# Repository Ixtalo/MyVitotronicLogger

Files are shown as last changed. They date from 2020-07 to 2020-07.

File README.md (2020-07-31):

MyVitotronicLogger
==================
Vissmann boiler logger with DIY OptoLink interface.  

AST, 12.03.2019

Motivation
----------
For a Vissmann boiler with a control interface Vitotronic 200 KW1 (V200KW1):   
* How much energy is consumed?
* How to monitor the boiler's temperatures?
* What is the boiler doing over time?
* How to interface with the boiler?

(DE) "Witterungsgeführte Kesselregelung für gleitend abgesenkte Kesselwassertemperatur"  

Solution Approach
-----------------
* Use the optical maintenance interface of the Vitotronic control interface.
	* <https://github.com/openv/openv/wiki/Die-Optolink-Schnittstelle>
	* KW Protocol, <https://github.com/openv/openv/wiki/Protokoll-KW>
* Use Arduino ESP8266 with a DIY optocoupler interface, see <https://github.com/openv/openv/wiki/Bauanleitung-ESP8266>
* Use VitoWiFi library
	* Arduino Library for ESP8266 to communicate with Viessmann boilers using a (DIY) serial optolink.
	* <https://github.com/bertmelis/VitoWiFi.git>
    * Many thanks for this gread library!
	* Based on the fantastic OpenV library

Requirements
------------
* ESP8266, e.g., Wemos D1 Mini
* OptoLink interface: <https://github.com/openv/openv/wiki/Bauanleitung-ESP8266>
* Libraries for:
	* Arduino, e.g., *Arduino IDE*
	* ESP8266 / Wemos D1 Mini
	* VitoWiFi, <https://github.com/bertmelis/VitoWiFi>
		* Tested working version was [Version 1.0.2 from 10.11.2018](https://github.com/bertmelis/VitoWiFi/tree/5d8a2d5b270df575b2cb3b8847567947bac362e9)
* Optional: RS232 USB cable for Serial1 observation (attach to D4)

Circuit / Wiring
----------------
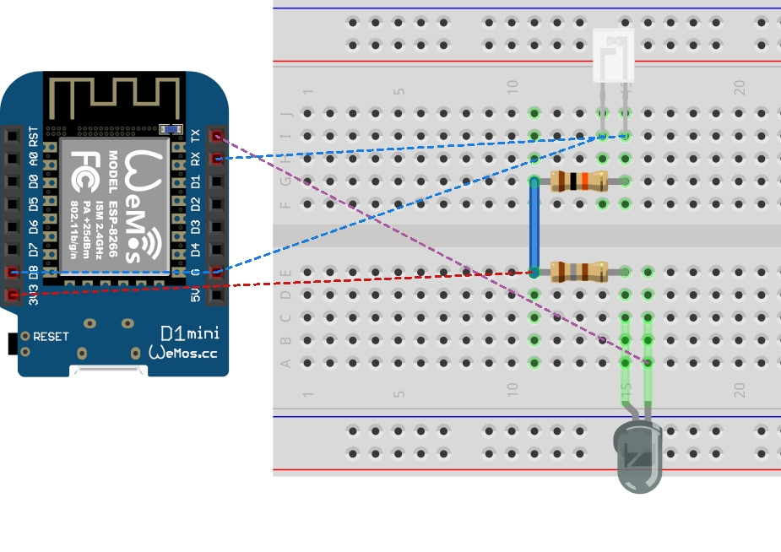
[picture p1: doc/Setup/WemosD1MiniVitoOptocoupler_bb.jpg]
Breadboard
  

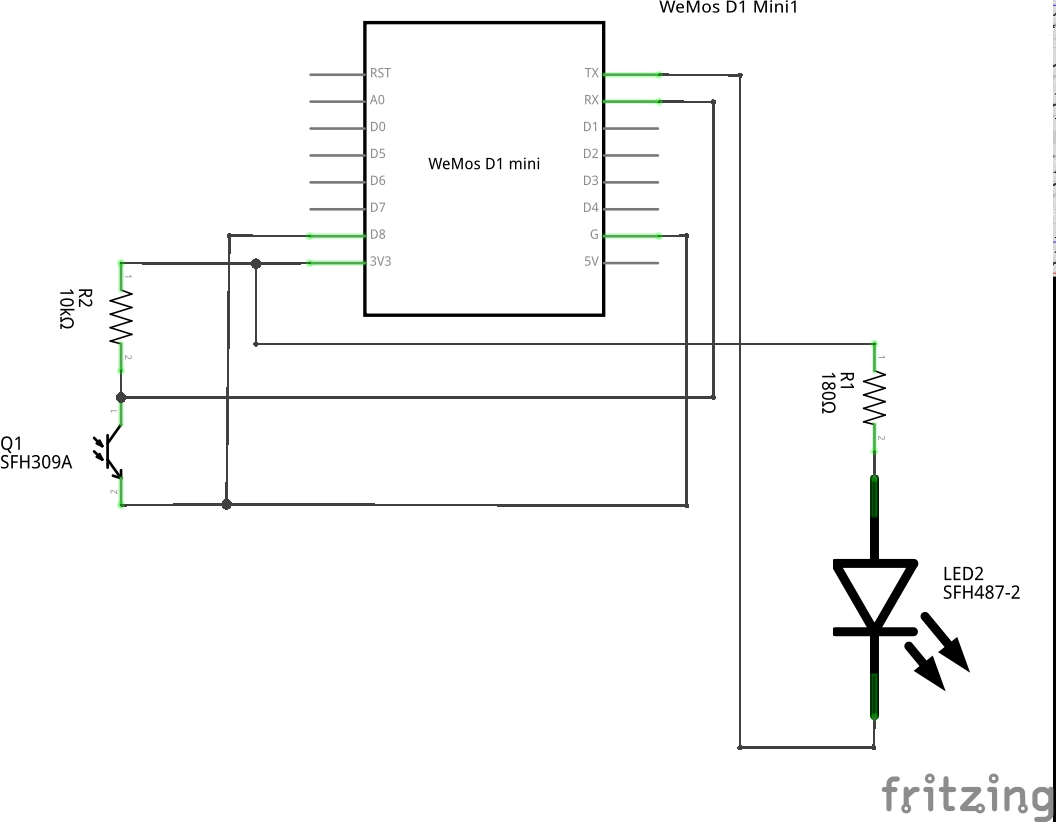
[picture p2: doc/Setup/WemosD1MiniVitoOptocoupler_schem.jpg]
Schematic


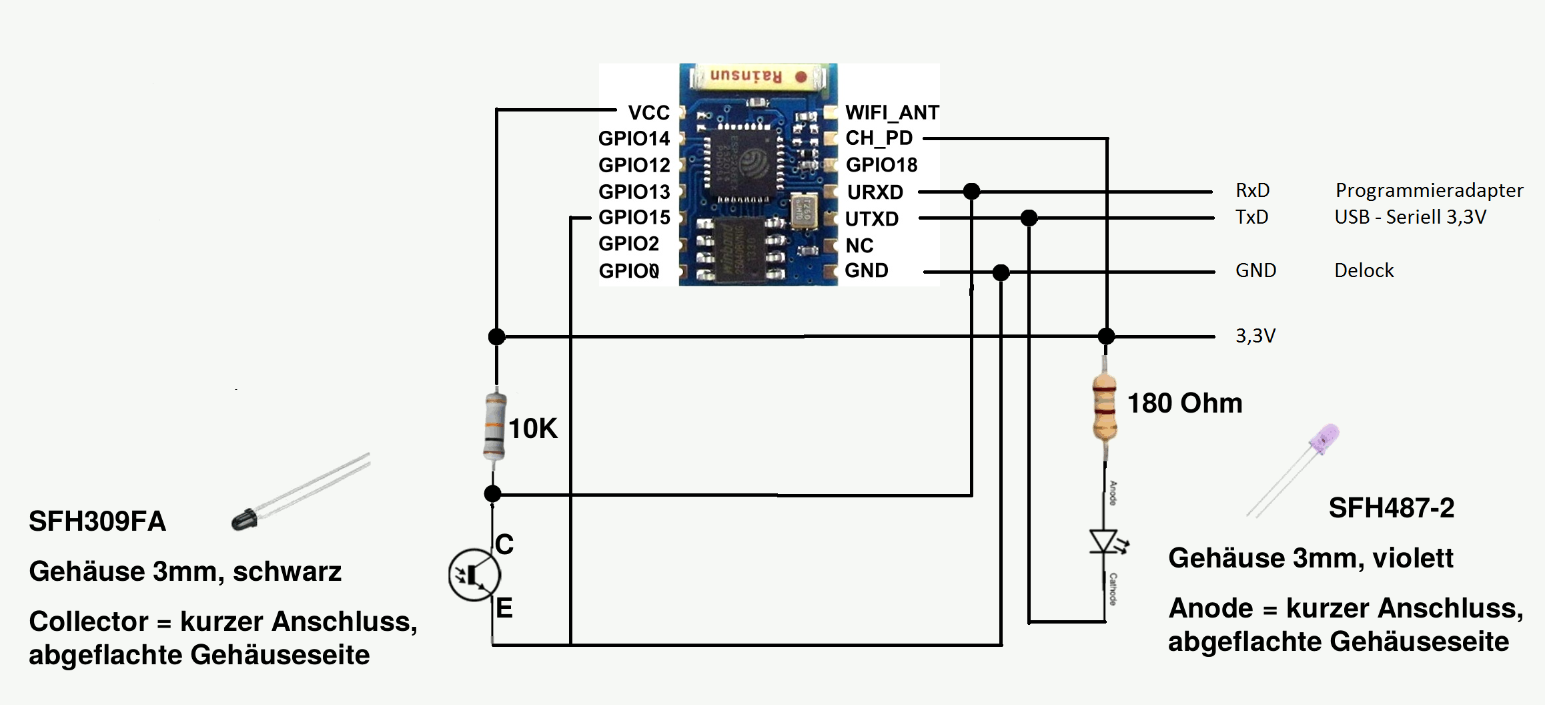
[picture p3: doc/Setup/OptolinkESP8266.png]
Wiring
  
(See also https://github.com/openv/openv/wiki/Bauanleitung-ESP8266)  

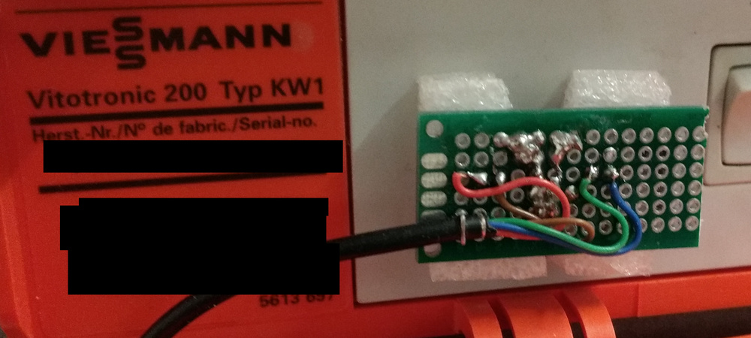
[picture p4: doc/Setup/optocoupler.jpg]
Sensor Breadboard Prototype


Debugging
---------------
1. Attach to opto coupler 
2. Attach RS232 USB cable to D4 to listen for Serial1 messages. **Serial1/UART1 TX pin is D4.**

**Do not connect to RX/TX because those are reserved for opto-coupler communication!**

For debugging the Serial1 Arduino software UART is being used.

  > Serial1.begin(115200);

All logging and status messages are being print using `Serial1.print`.  
Serial1 uses UART1 which is a transmit-only UART.  

Development
---------------

### vitowifitests
Testing project to test the OptoLink interface.
1. Attach to opto coupler 
2. Attach RS232 USB cable to D4 to listen for Serial1 messages. **Serial1/UART1 TX pin is D4.**

Example output:
```
temperature - boilerTemp is 32.4
temperature - STS1 is 48.5
temperature - RTS is 20.0
temperature - AGTS is 20.0
temperature - RLTS is 20.0
temperature - VLTS is 20.0
temperature - setRoomTemp is 309.2
temperature - setRoomReducedTemp is 513.2
burner - runHours is 10272.3
burner - starts is 199182
operation - currentOperatingMode is 2
pump - a1m1Pump is true
pump - storePump is false
pump - circuitPump is false
```

### vitowifimqtt
Working Arduino project.
Sends collected data from OptoLink interface to MQTT server.  

Example output:
```
/esp/VitoWiFi/ip 192.168.1.108
/esp/VitoWiFi/outsideTemp 8.9
/esp/VitoWiFi/boilerTemp 56.6
/esp/VitoWiFi/STS1 47.7
/esp/VitoWiFi/RTS 20.0
/esp/VitoWiFi/AGTS 20.0
/esp/VitoWiFi/RLTS 20.0
/esp/VitoWiFi/VLTS 20.0
/esp/VitoWiFi/setRoomTemp 309.2
/esp/VitoWiFi/setRoomReducedTemp 538.8
/esp/VitoWiFi/runHours 10274.3
/esp/VitoWiFi/starts 199237
/esp/VitoWiFi/currentOperatingMode 2
/esp/VitoWiFi/a1m1Pump true
/esp/VitoWiFi/storePump false
/esp/VitoWiFi/circuitPump false
```

### Pictures

My setup and wiring:
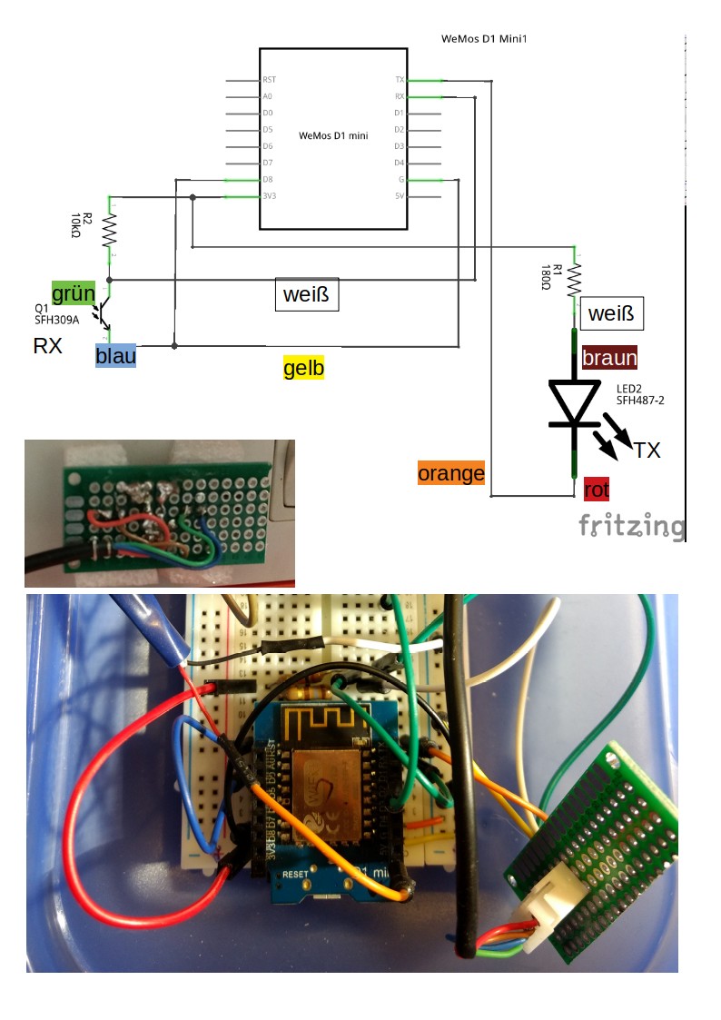
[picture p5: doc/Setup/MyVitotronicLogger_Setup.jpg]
My setup


Links
-----
* [OpenV](https://github.com/openv/openv/wiki/)
* [Anbindung der Heizungssteuerung über Optolink](https://www.harrykellner.de/index.php/projekte2/81-optolink)
* [Talking to Viessmann Vitodens 200](https://www.edom-plc.pl/index.php/en/1-wire-i-rpi-en/175-komunikacja-z-viessmann-em-vitodens-200)
* <http://www.rainer-rebhan.de/proj_vvt_manager.html>

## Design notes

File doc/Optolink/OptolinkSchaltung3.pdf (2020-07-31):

## Bauanleitung für eine Optolink Schnittstelle

## 1. Schaltplan (Schaltung 3)

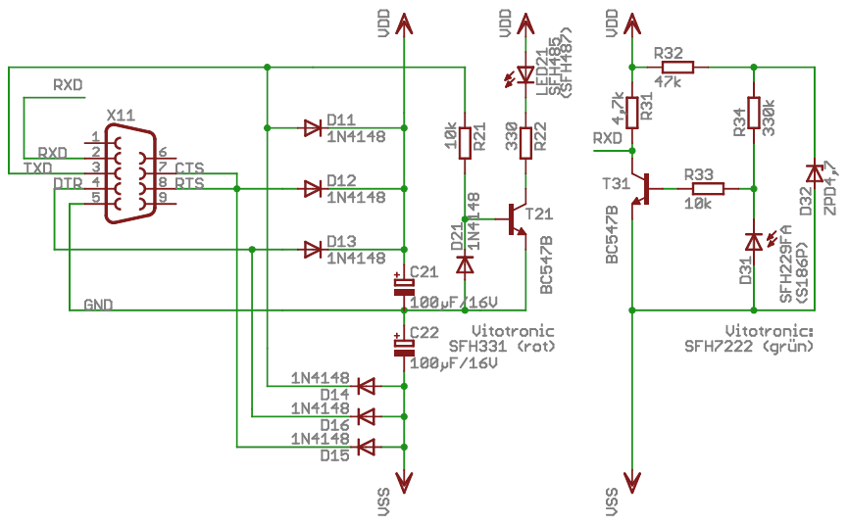
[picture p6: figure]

Bild 1: Schaltplan für Optolink Schnittstelle

Die Schaltung wurde im Vergleich zur ursprünglichen Schaltung in folgenden Punkten modifiziert:
- Einführung einer zusätzlichen negativen Spannung für die Empfangsdiode, um die Pegeldefinitionen der seriellen Schnittstelle einzuhalten (C22, D14-D16).
- Die Empfangsdiode wurde an die richtige Stelle versetzt und gedreht (Betrieb in Sperrrichtung).

## Stückliste

Bauteil | Wert | Beschreibung
C21 | 100µF/16V | Elektrolytkondensator
C22 | 100µF/16V | Elektrolytkondensator
D11-D16 | 1N4148 | Diode
D21 | 1N4148 | Diode
D31 | SFH229FA | Photodiode
D32 | ZPD4,7 | Zenerdiode 4,7 V
LED21 | SFH485 | Infrarot LED (5 mm), alternativ SFH487 (3 mm)
R21 | 10k | Widerstand
R22 | 330 | Widerstand
R31 | 4,7k | Widerstand
R32 | 47k | Widerstand
R33 | 10k | Widerstand
R34 | 330k | Widerstand
T21 | BC547B | NPN Transistor
T31 | BC547B | NPN Transistor
X11 | - | SUB-D Stecker 9-pol (weibl.)
| Stecker-
| gehäuse | Längeres Steckergehäuse für SUB-D Stecker
| Gehäuse | Bopla U50 50x50x30 mm
| Kabel | 5-adriges Kabel mit Schirm
| Zugentlastung | Gummitülle für Zugentlastung
Alle Widerstände 0,25 W, Gehäuse bestellbar bei Conrad (Bopla Nr. 06050000, Conrad Nr. 519979-62).
Seite 1 von 4 | Optolink Schaltung 3 V1.0

Technische Daten der Bauteile, etc.

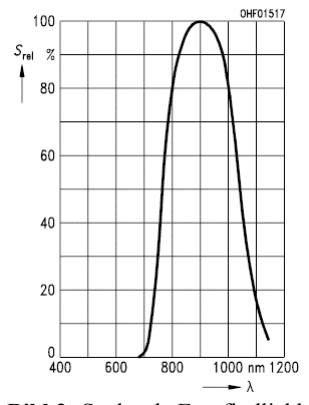
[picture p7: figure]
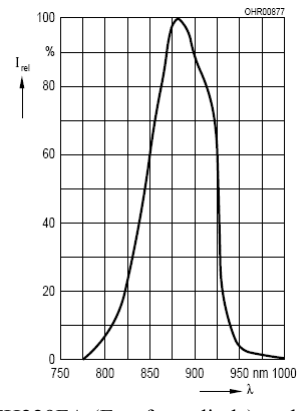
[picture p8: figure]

Bild 2: Spektrale Empfindlichkeit SFH229FA (Empfangsdiode) und spektrale Emission SFH485 (Sendediode)

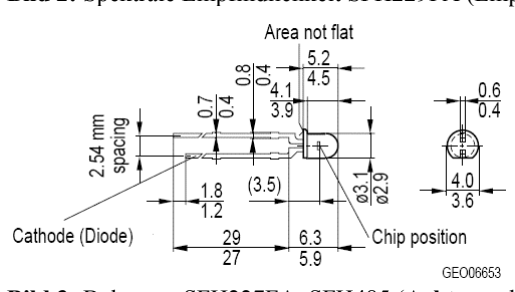
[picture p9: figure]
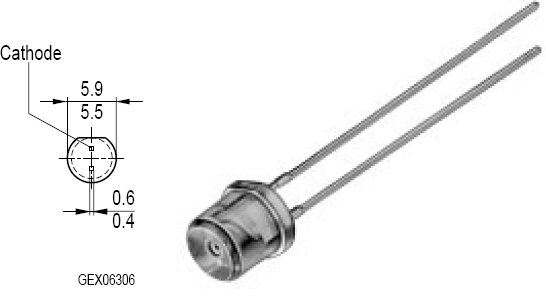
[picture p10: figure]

Bild 3: Belegung SFH227FA, SFH485 (Achtung: langes Beinchen ist Kathode!)

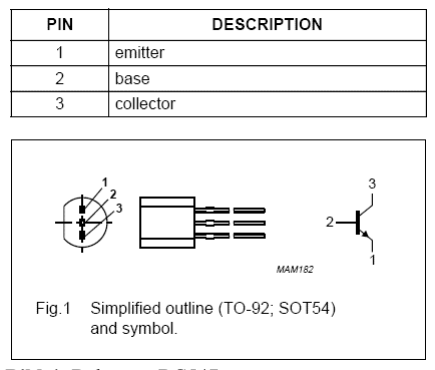
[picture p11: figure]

Bild 4: Belegung BC547

## 2. Mechanischer Aufbau

Im Folgenden soll nur stichwortartig der Aufbau geschildert werden, näheres bitte den Bildern entnehmen.
- An der Regelung die Maße für die Löcher und das V über ein Papier abnehmen und auf das Gehäuse übertragen.
- Die zwei Löcher für die Sende- bzw. Empfangsdiode bohren (Durchmesser und Position beachten).
- Das V in der Vitotronic mit Hilfe eines Kunststoffes, der für Abdeckung von Ausbrüchen in Zählerschränken verwendet wird, gestalten: In den Enden des V zwei Löcher bohren, die Abdeckung falten, mit dem Teppichmesser bearbeiten (zwei Zapfen stehen lassen) und in das Gehäuse einkleben.
- Die Schaltung C21, C22, D11-16 auf einer Lochrasterplatine, den Rest auf einer anderen Lochrasterplatine aufbauen.
- Beide mit Kabel verbinden und in die jeweiligen Gehäuse einbauen, Zugentlastung nicht vergessen.
Seite 2 von 4 | Optolink Schaltung 3 V1.0

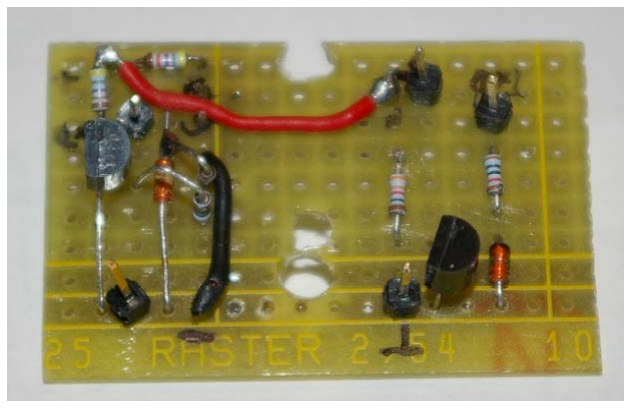
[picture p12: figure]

Bild 5: Lochrasterleiterplatte (Sende-/Empfangsteil)

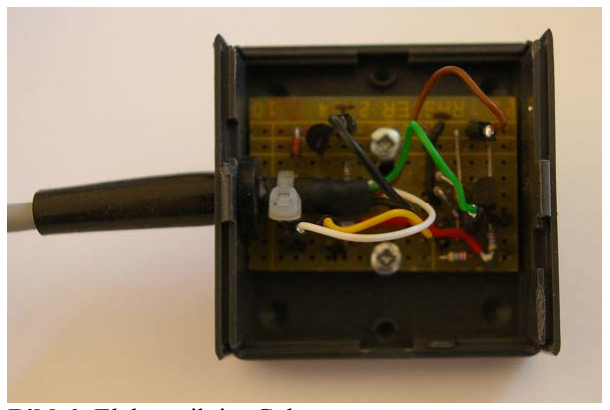
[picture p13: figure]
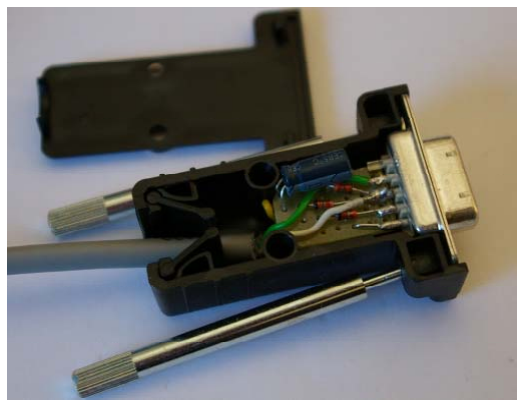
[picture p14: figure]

Bild 6: Elektronik im Gehäuse

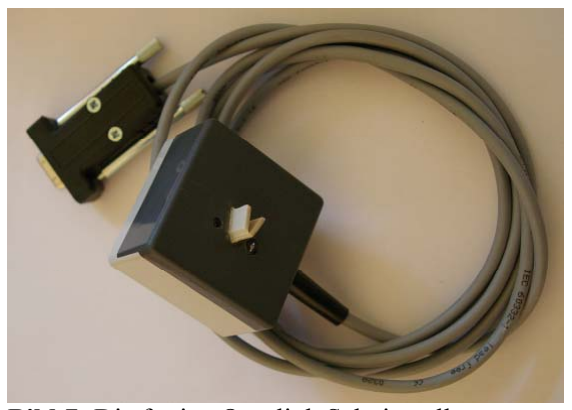
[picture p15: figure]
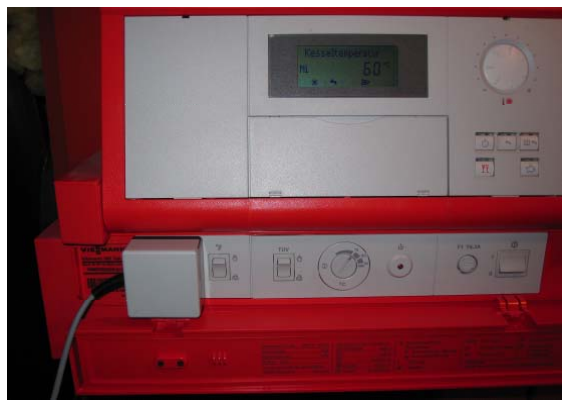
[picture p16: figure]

Bild 7: Die fertige Optolink Schnittstelle

## 3. Inbetriebnahme

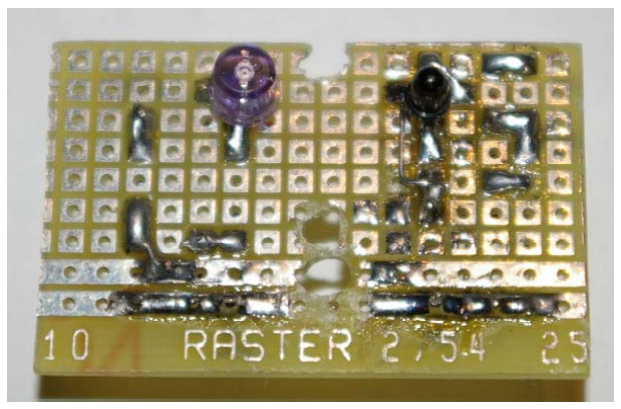
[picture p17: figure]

Wenn nach dem Aufbau soweit alles in Ordnung ist, kann die Schaltung statisch mit dem COM Tester von Arne Rossius¹
(aktuelle Version V1.0) getestet werden. Programm in beliebiges Verzeichnis auspacken und starten. COM Port auswählen, DTR und RTS an- bzw. ausschalten und die pos. bzw. neg. Versorgungsspannung messen. Dann TXD anschalten und messen, ob sich der Pegel am Kollektor von T21 ändert. Das Empfangen von Daten kann mit diesem Programm nicht getestet werden.

1 http://elektronik-kompendium.de/public/arnerossius/programme/windows/sertest1.zip, Stand 07.01.2010

Seite 3 von 4 | Optolink Schaltung 3 V1.0

Für den Test des Empfangs können verschiedene Terminalprogramme verwendet werden:
- COMTestSerial der Fa. MicroRidge (aktuelle Version 2.1)²
- SerialPortTerminal³
- RS232Test

4

Die Schnittstelle wird mit 4800 bps, 8 Bits, Even Parity, 2 Stopbits (4800, 8, E, 2) betrieben. Hardware Handshake wird nicht unterstützt. Software Handshake (XON/XOFF) wird nicht unterstützt und muss abgeschaltet werden, da sonst eine Datenbyte, das zufällig dem XOFF Zeichen entspricht, das Handshake stoppen könnte.

Terminalprogramm installieren, serielle Schnittstelle auswählen und Parameter für die Schnittstelle einstellen. Wichtig ist auch, dass man RTS oder DTR anschaltet, da ansonsten keine Spannung zur Verfügung steht. Wenn dann in regelmäßigen Abständen 05hex (ca. alle 2 ... 5 s) im Terminalprogramm angezeigt wird, so empfängt das Terminalprogramm korrekt die Daten, die von der Viessmann Regelung kommen. Die Optolink Schaltung funktioniert.

## 4. Rechtliches

Die einwandfreie Funktion der Schaltung wurde bei mir an einer Viessmann Vitotronik 200 KW1 nachgewiesen. Trotzdem hafte ich nicht für die ordnungsgemäße Funktion der Schaltung beim Nachbau. Ich schließe auch jede Haftung für Schäden, die sich beim Nachbau oder Betrieb der Schaltung ergeben, ausdrücklich aus.
Sollten sich Fehler in der Dokumentation eingeschlichen haben oder Fragen zum Aufbau auftauchen, dann bitte ich um eine kurze Mail an

palaretta@gmx.de

Ich bitte um Verständnis, wenn die Beantwortung der Fragen nicht sofort erfolgt.

Raum Heilbronn, 07.01.2010, Peter

2 http://www.microridge.com/comtestserial.htm, Stand 07.01.2010 3 http://www.logview.info/cms/download.php?f=81e020332a53570debd35e46b8f23b84, Stand 07.01.2010 4 http://openv.wikispaces.com/file/view/RS232Test.zip, Stand 07.01.2010, Programm funktioniert bei mir nicht!

Seite 4 von 4 | Optolink Schaltung 3 V1.0

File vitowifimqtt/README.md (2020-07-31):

# VitoWifiMqtt

Read Vissmann boiler parameters with a ESP8266 and a DIY opto-coupler interface.  

## Prerequisites

- VisualStudio Code (VSCode)
- PlatformIO

## How-To Build
1. Generate private key for signing (`private.key`). See https://arduino-esp8266.readthedocs.io/en/latest/ota_updates/readme.html#signed-binary-prerequisites

    > openssl genrsa -out private.key 2048
    > openssl rsa -in private.key -outform PEM -pubout -out public.key

    Adjust option `signing_private_key` in `platformio.ini` to point to you `private.key` file.

    > signing_private_key = $SMARTHOME_WORKSPACE/private.key 

2. Open folder in VSCode
3. Open PlatformIO
4. Build
5. The signed binary is `vitowifimqtt/.pio/build/d1_mini/firmware.bin.signed`

## Debug Output

### NoWiFi
```
SDK:2.2.2-dev(38a443e)/Core:2.6.3=20603000/lwIP:STABLE-2_1_2_RELEASE/glue:1.2-16-ge23a07e/BearSSL:89454af
Boot mode: 1
Reset reason: Deep-Sleep Wake
Connecting WiFi ...
scandone
no Tintagel.dev found, reconnect after 1s
reconnect
scandone
no Tintagel.dev found, reconnect after 1s
reconnect
scandone
no Tintagel.dev found, reconnect after 1s
WiFi wifi_res: 1
DeepSleep! (30.0 sec)
del if0
usl
enter deep sleep
```

### WiFi, No DHCP
```
DK:2.2.2-dev(38a443e)/Core:2.6.3=20603000/lwIP:STABLE-2_1_2_RELEASE/glue:1.2-16-ge23a07e/BearSSL:89454af
Boot mode: 1
Reset reason: Deep-Sleep Wake
tstart: 85
Connecting WiFi ...
scandone
scandone
state: 0 -> 2 (b0)
state: 2 -> 3 (0)
state: 3 -> 5 (10)
add 0
aid 1
cnt 

connected with Tintagel.dev, channel 1
dhcp client start...
WiFi wifi_res: -1
DeepSleep! (30.0 sec)
state: 5 -> 0 (0)
rm 0
del if0
usl
enter deep sleep
```

### WiFi, DHCP, No MQTT
```
SDK:2.2.2-dev(38a443e)/Core:2.6.3=20603000/lwIP:STABLE-2_1_2_RELEASE/glue:1.2-16-ge23a07e/BearSSL:89454af
Boot mode: 1
Reset reason: Deep-Sleep Wake
tstart: 83
Connecting WiFi ...
scandone
state: 0 -> 2 (b0)
state: 2 -> 3 (0)
state: 3 -> 5 (10)
add 0
aid 1
cnt 

connected with Tintagel.dev, channel 1
dhcp client start...
ip:192.168.99.128,mask:255.255.255.0,gw:192.168.99.1
WiFi connect result time: 4125
WiFi wifi_res: 3
OTA update check ...
[OTA]  HTTP update fatal error code -1
HTTP_UPDATE_FAILD Error (-1): HTTP error: connection refused
OTA update check END.
Attempting MQTT connection...failed, rc=-2
failed, rc=-2
pm open,type:2 0
failed, rc=-2
WiFi disconnect ...
state: 5 -> 0 (0)
rm 0
pm close 7
DeepSleep! (30.0 sec)
del if0
usl
enter deep sleep
```

### OTA HTTP request
```
Connection from 192.168.99.128 52336 received!
GET /firmware.bin HTTP/1.0
Host: 192.168.99.1:8266
User-Agent: ESP8266-http-Update
Connection: close
x-ESP8266-Chip-ID: 2713345
x-ESP8266-STA-MAC: xxx
x-ESP8266-AP-MAC: xxx
x-ESP8266-free-space: 2797568
x-ESP8266-sketch-size: 346400
x-ESP8266-sketch-md5: e4fa3ca3d5b1ca2a9892513ec5f4b3ee
x-ESP8266-chip-size: 4194304
x-ESP8266-sdk-version: 2.2.2-dev(38a443e)
x-ESP8266-mode: sketch
Content-Length: 0
```

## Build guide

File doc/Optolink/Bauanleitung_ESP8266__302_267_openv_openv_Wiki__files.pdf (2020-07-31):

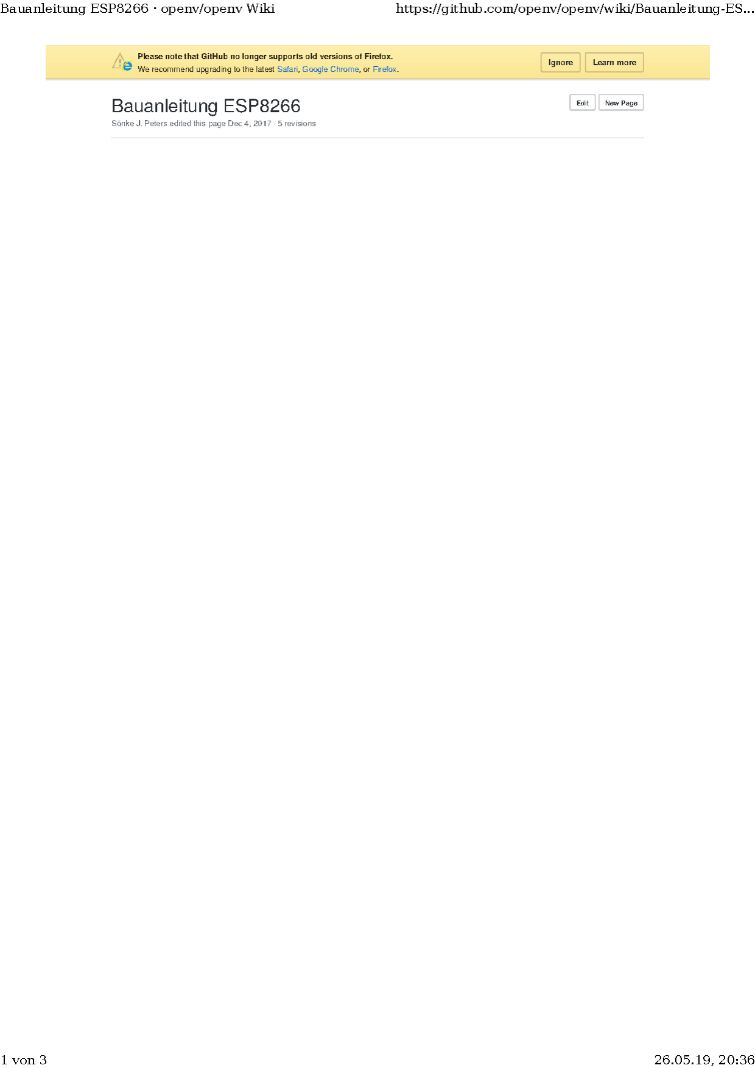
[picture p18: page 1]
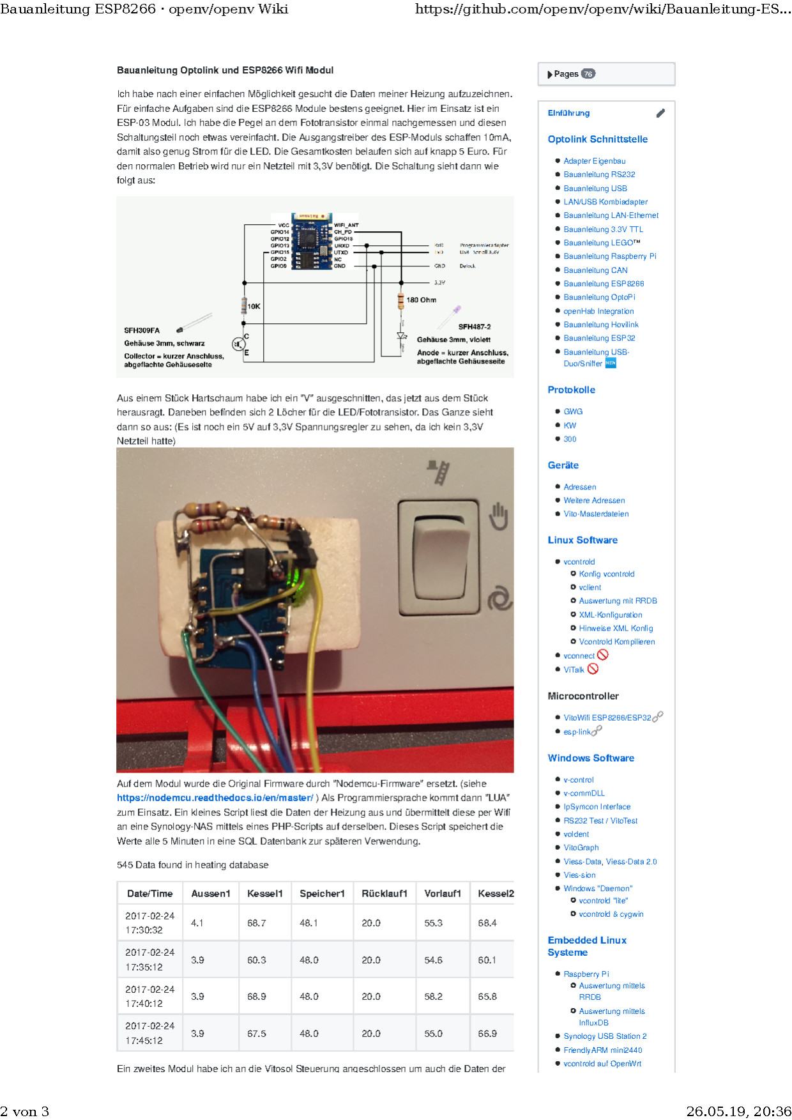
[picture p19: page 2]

✁✂✁✄☎✆✝✞✂✄✟ ✠✡☛☞✌✍✍ ✎ ✏✑✆✄✒✓✏✑✆✄✒ ✔✝✕✝ | ✖✞✞✑✗✘✓✓✟✝✞✖✂✙✚✛✏✜✓✏✑✆✄✒✓✏✑✆✄✒✓✢✝✕✝ ✓✁✂✁✄☎✆✝✞✂✄✟✣✠✡✚✚✚
✤ ✒✏✄ ✤ | ✌✍✚✥✦✚✧★✩ ✌✥✘✤✍

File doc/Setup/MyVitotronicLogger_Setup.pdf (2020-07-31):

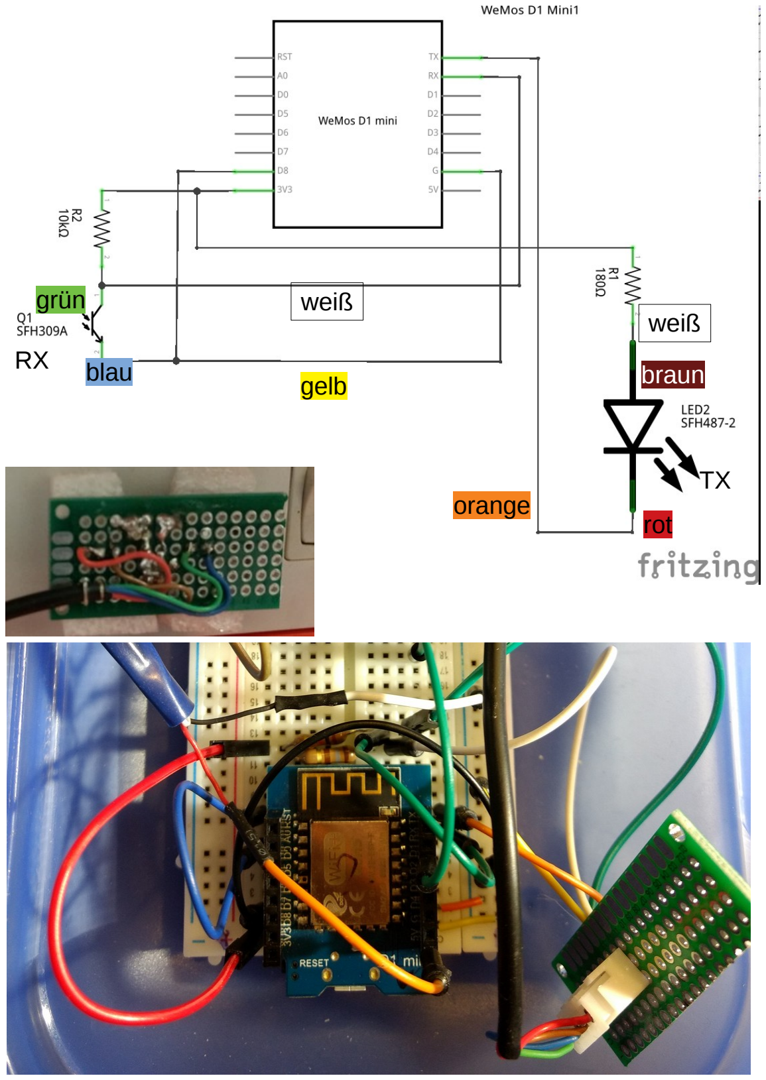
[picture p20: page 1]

braun

rot

TX

RX

grün

blau

orange

weiß
weiß

gelb

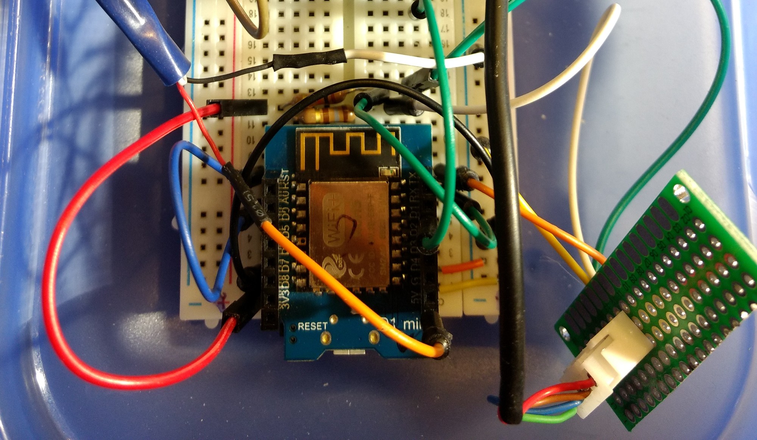
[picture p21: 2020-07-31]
doc/Setup/breadboard_20200102.jpg

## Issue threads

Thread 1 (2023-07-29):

SFH487-2 alternative

Jumbo125, 2023-07-29:
Hello

I  want to build a optolink adapter with my wemos D1

I can't pay a SFH487-2. Is there a alternative???

Thank you for your help

Jumbo125, 2023-08-05:
hello
i found a alternative. thank you to arduino-forum1

can you tell me, why you wiring D8 to the RX?

Ixtalo, 2023-09-07:
> hello i found a alternative. thank you to arduino-forum1
>
> can you tell me, why you wiring D8 to the RX?

As quoted in the `README.md`: I'm following the wiring from https://github.com/openv/openv/wiki/Bauanleitung-ESP8266.

Closed 2023-09-07.

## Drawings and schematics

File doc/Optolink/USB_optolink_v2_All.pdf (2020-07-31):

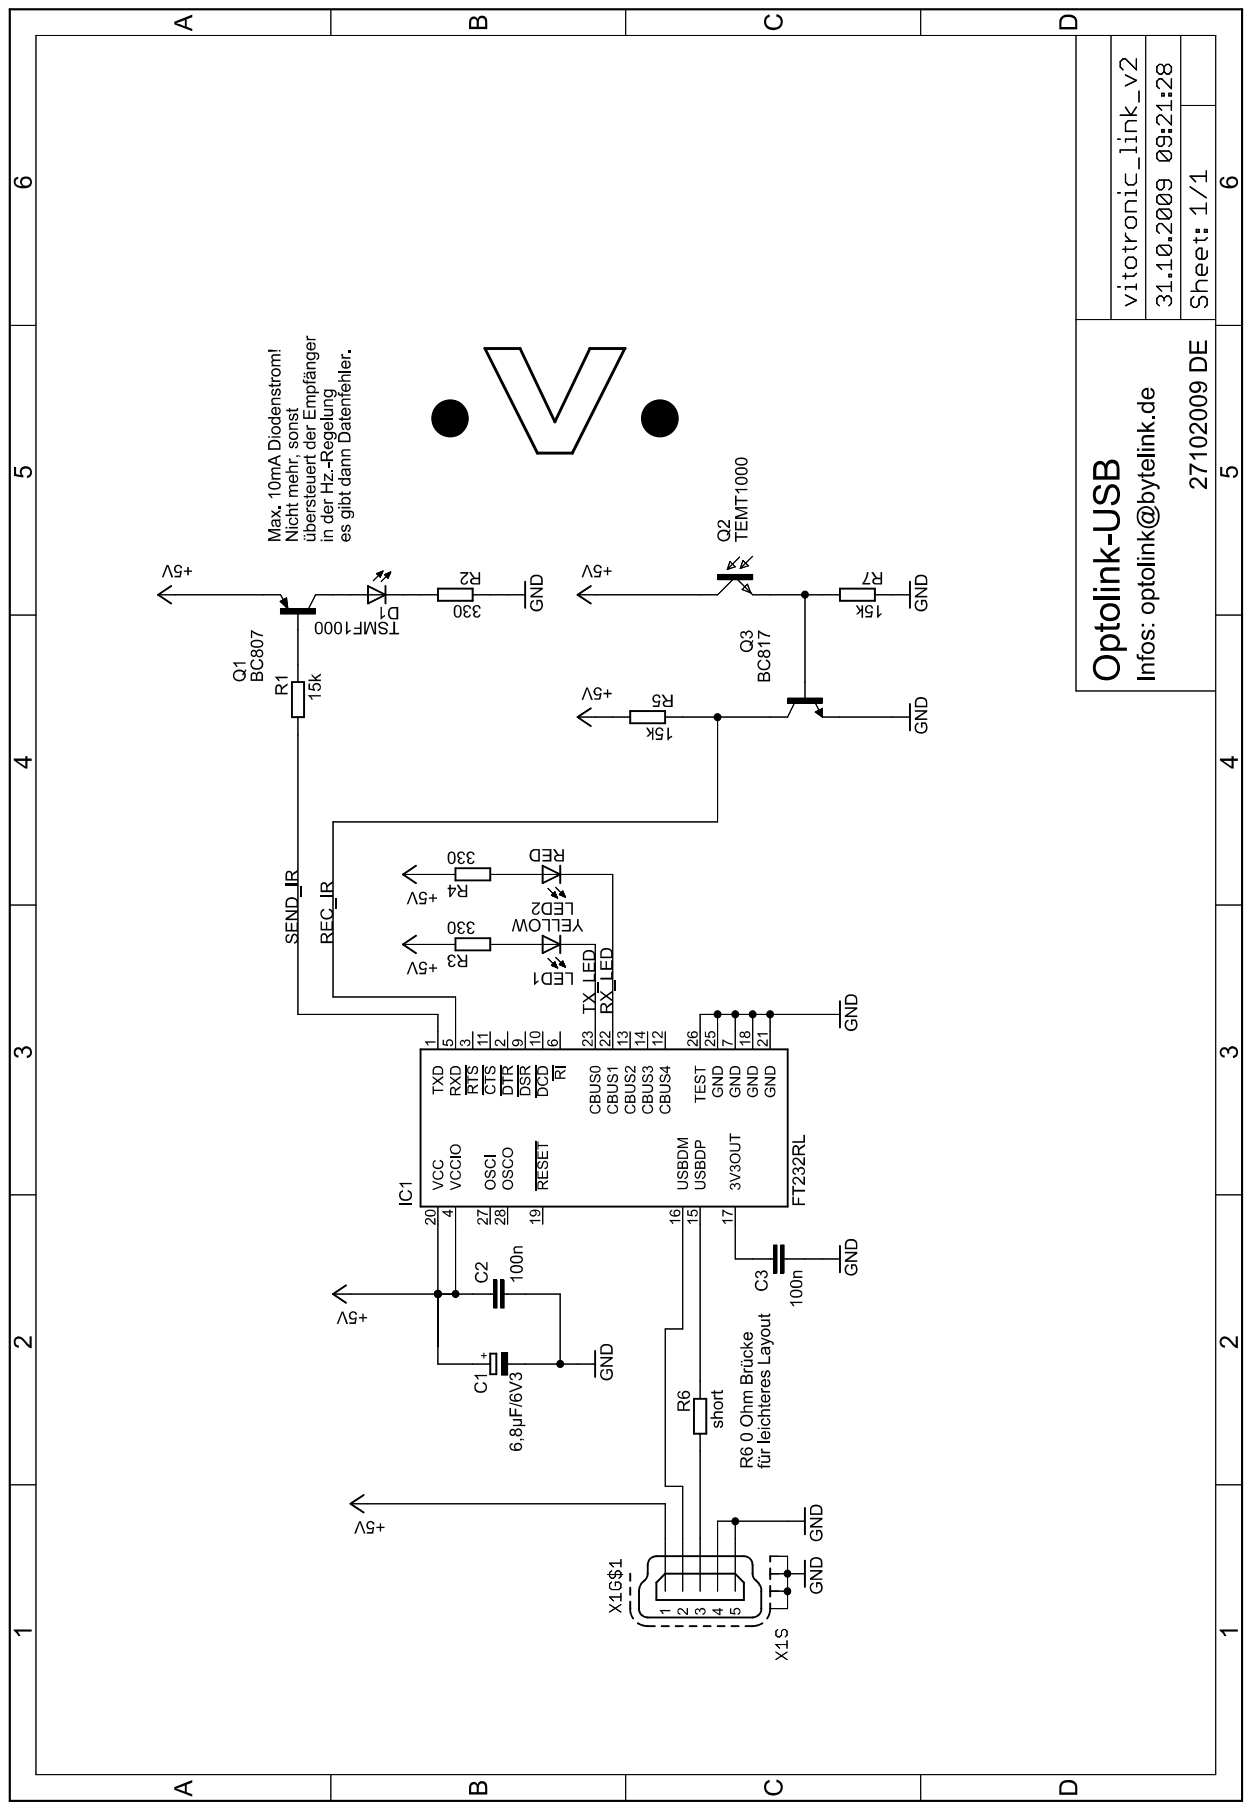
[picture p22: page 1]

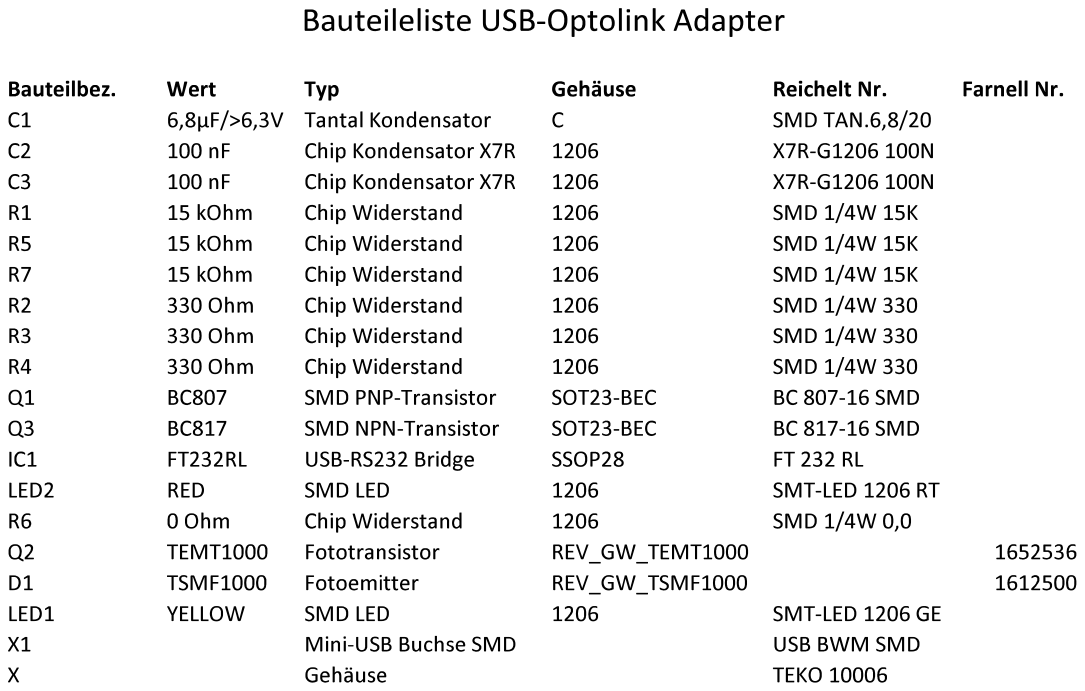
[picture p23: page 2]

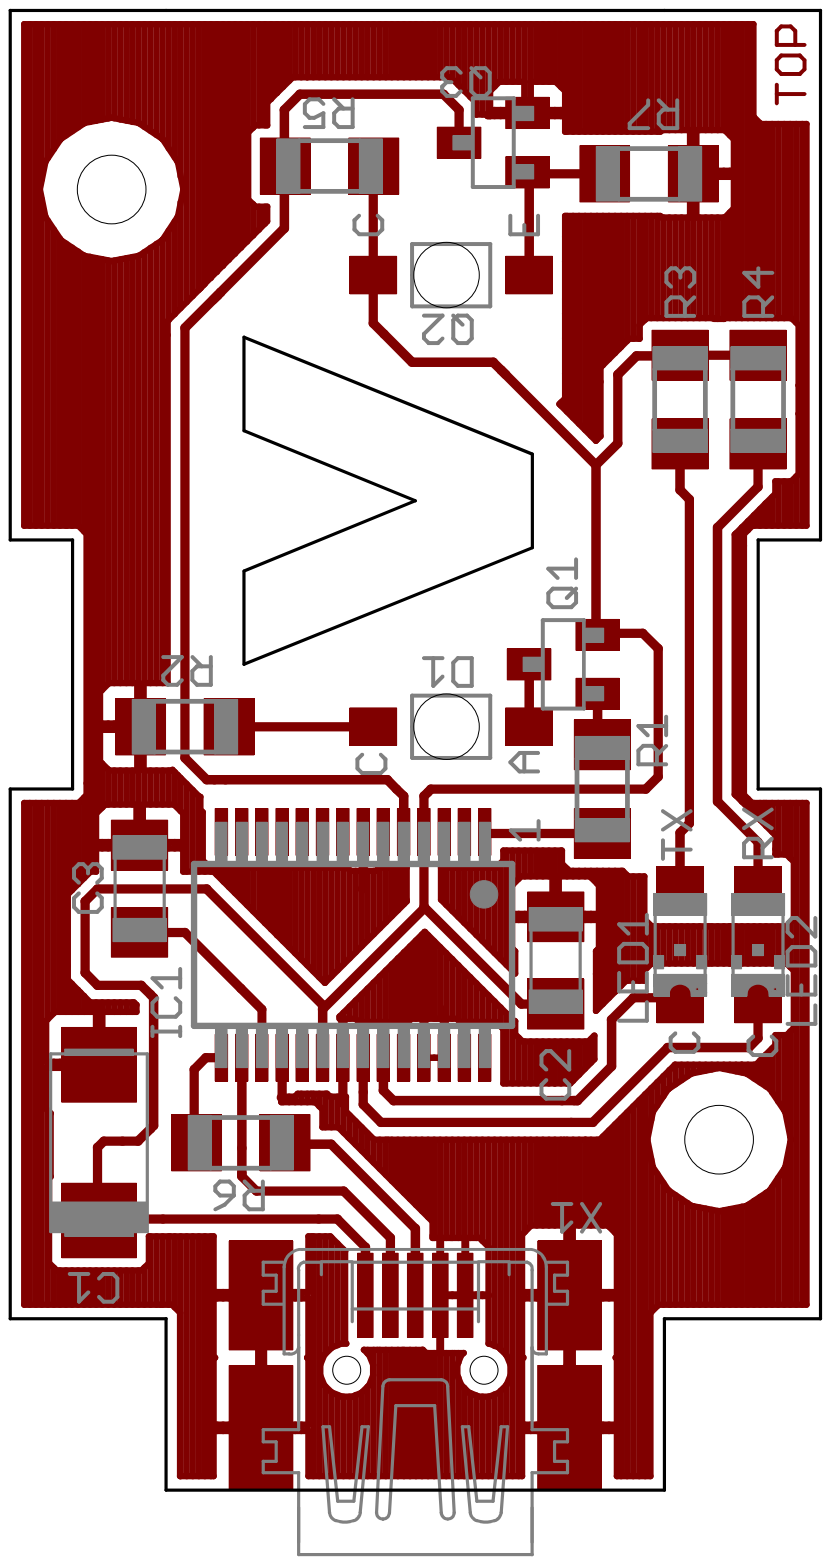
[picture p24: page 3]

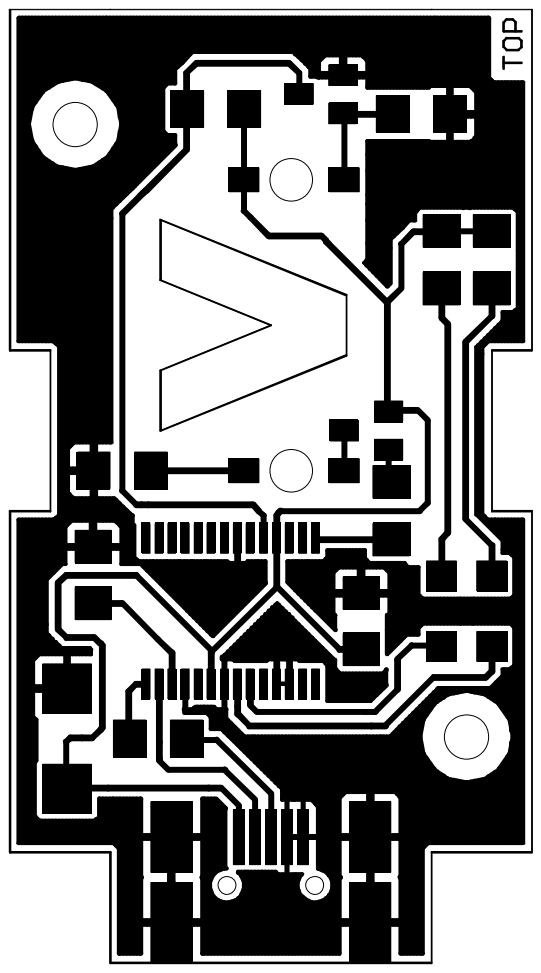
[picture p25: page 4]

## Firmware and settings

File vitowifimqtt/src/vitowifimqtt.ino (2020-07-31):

/*
 * MyVitotronicLogger
 * Vissmann boiler logger with DIY OptoLink interface.  
 * AST, 03/2019 (initial version)
 * 
 * Based on https://github.com/bertmelis/VitoWiFi.git
 * 
 */
#include <Arduino.h>
#include <ESP8266WiFi.h>
#include <ESP8266HTTPClient.h>
#include <ESP8266httpUpdate.h>
#include <ESP8266mDNS.h>
#include <PubSubClient.h> // MQTT, https://pubsubclient.knolleary.net/
#include <VitoWiFi.h>     // https://github.com/bertmelis/VitoWiFi.git

// define an own macro for serial output which is only active
// if boolean debug variable is true
// this reduced the CPU time used for printing debug output
#define SER if (debug) Serial1

// debug mode activation switch
// it is set in setup() and can be set via hardware
// by wiring DEBUG_PIN to ground
#define DEBUG_PIN D1
bool debug = false; // possibly changed in setup()

// hostname/clientId
const char *deviceName = "ESP-VitoWiFi";

// declare credentials and settings in external header file
// const char* WIFI_SSID = "...";
// const char* WIFI_PASS = "...";
// const char* MQTT_HOST = "192.168.3.1";
// const uint16_t MQTT_PORT = 1883;
// const char* MQTT_USER = "...";
// const char* MQTT_PASS = "...";
// const char* OTA_HOST "192.168.99.1"
// const char* OTA_PROTOCOL "http"
// const uint16_t OTA_PORT 8266
// const char* OTA_PATH "firmware.bin"
// const char* OTA_VERSION ""
#define SENSORNODE  // activate MQTT settings
#define OTA // activate OTA settings
#include "mysettings.h"



///------------------------------------------------------------------
/// Data Points
///------------------------------------------------------------------
/// Vitotronik 200 Typ KW1
/// https://github.com/openv/openv/wiki/Adressen
/// kd_list_nr2_20110719.pdf, "Datenpunktliste Vitotronic 200-H; 050 (Typ HK1W)_20AA"

// number of datapoints (must be identical to the defined variables)
const uint8_t numDp = 17;
// number of processed datapoints (will be set later while running)
uint8_t iDpProcessed = 0;

// Aussentemperatur Tiefpass [R]
// Currently calculated low pass outside temperature, Time constant 30 minutes.
DPTemp outsideTemp("outsideTemp", "temperature", 0x5525); // 2-Byte, -60..60
// 0x0800 2-byte ATS Aussentemperatur (Sensor 1)
DPTemp atsTemp("ATS", "temperature", 0x0800);
// Kesseltemperatur Tiefpass [R]
DPTemp boilerTemp("boilerTemp", "temperature", 0x0810); // 2-Byte, 0..127
// WW-Temperatur (Speicher) [R]
DPTemp store1Temp("STS1", "temperature", 0x0812); // 2-Byte, 0..150
// Raumtemperatur A1M1 Tiefpass RTS [R]
DPTemp roomTemp("RTS", "temperature", 0x0896); // 2-Byte, 0..127
// Abgastemperatur Tiefpass AGTS [R]
DPTemp agtsTemp("AGTS", "temperature", 0x0816); // 2-Byte
// Rücklauftemperatur (17A) [R]
DPTemp rltsTemp("RLTS", "temperature", 0x080A); // 2-Byte
// Vorlauftemperatur (17B) [R]
DPTemp vltsTemp("VLTS", "temperature", 0x080C); // 2-Byte
// 0x0802 2-byte KTS Kesseltemperatur (Sensor 3)
DPTemp ktsTemp("KTS", "temperature", 0x0802);
// Betriebsstunden Stufe 1
DPHours boilerRunHours("runHours", "burner", 0x08A7); // 4-Byte, 0..1150000
// Brennerstarts [R]
DPCount boilerRuns("starts", "burner", 0x088A); // 4-Byte, 0..1150000
// aktuelle Betriebsart A1M1 [R]; 0=Standby mode, 1=Reduced mode, 2=Standard mode, 3=Standard mode
DPMode currentOperatingMode("currentOperatingMode", "operation", 0x2500); // 1-Byte, 0..3
// Heizkreispumpe A1M1 [R]
DPStat aim1Pump("a1m1Pump", "pump", 0x2906);
// Speicherladepumpe [R]
DPStat storePump("storePump", "pump", 0x0845);
// Zirkulationspumpe [R]
DPStat circuitPump("circuitPump", "pump", 0x0846);

/*
room temp
22	309.4
21	258.1
18	257.8	283.4

reduced room temp
10	615.4
11	615.5
12	615.6
*/
// Raumtemperatur Soll
DPTemp setRoomTemp("setRoomTemp", "temperature", 0x2306); // 1-Byte, 3..37
// Reduizierte Raumtemperatur Soll [RW]
DPTemp setRoomReducedTemp("setRoomReducedTemp", "temperature", 0x2307); // 1-Byte, 3..37

// 0x55E3 1-byte aktuelle Leistung %
// DOES NOT SEEM TO WORK, ALWAYS 255// DPMode currentPower("currentPower", "operation", 0x55E3);
// 0x5555 1-byte Drosselklappenposition (0..100%)
// DOES NOT SEEM TO WORK, ALWAYS 255// DPMode throttlePosition("throttlePosition", "operation", 0x5555);

// DOES NOT WORK DPTemp store2Temp("store2Temp", "temperature", 0x0813);  // 2-Byte, 0..150
// (equal to room temp) DPTemp outletTemp("outletTemp", "temperature", 0x0814);  // 2-Byte, 0..150
// DOES NOT WORK (-0.1) DPTemp setFlowTemp("setFlowTemp", "temperature", 0x2544);
// DOES NOT WORK (-0.1) DPTemp setBoilerTemp("setBoilerTemp", "temperature", 0x555A); // 2-Byte
// DOES NOT WORK (-0.1) DPTemp setExtRoomTemp("setExtRoomTemp", "temperature", 0x2321);
// DOES NOT WORK (255) DPMode operatingMode("operatingMode", "operation", 0x2323); // 1-Byte, 0..3

/*
Example output:

temperature - boilerTemp is 32.4
temperature - STS1 is 48.5
temperature - RTS is 20.0
temperature - AGTS is 20.0
temperature - RLTS is 20.0
temperature - VLTS is 20.0
temperature - setRoomTemp is 309.2
temperature - setRoomReducedTemp is 513.2
burner - runHours is 10272.3
burner - starts is 199182
operation - currentOperatingMode is 2
pump - a1m1Pump is true
pump - storePump is false
pump - circuitPump is false

*/

///------------------------------------------------------------------
///------------------------------------------------------------------
///------------------------------------------------------------------

WiFiClient wifiClient;
PubSubClient mqttClient(wifiClient);
VitoWiFi_setProtocol(KW);
const ulong vitoTimeout = 10 * 1000UL; // max 10 sec 
bool vitoDoRead = false;
ulong tstart = 0;

// OTA signing
BearSSL::PublicKey signPubKey(pubkey);
BearSSL::HashSHA256 hash;
BearSSL::SigningVerifier sign(&signPubKey);

// OTA callbacks
void ota_update_started()
{
  SER.println("[OTA]  HTTP update process started");
}

void ota_update_finished()
{
  SER.println("[OTA]  HTTP update process finished");
}

void ota_update_progress(int cur, int total)
{
  SER.printf("\r[OTA]  HTTP update process at %d of %d bytes...", cur, total);
}

void ota_update_error(int err)
{
  SER.printf("[OTA]  HTTP update fatal error code %d\n", err);
}

bool mqtt_connect(const char *clientId, const uint8 n_attempts = 3)
{
  SER.print(F("Attempting MQTT connection..."));
  SER.flush();
  for (size_t i = 0; i < n_attempts; i++)
  {
    if (mqttClient.connected())
    {
      return true;
    }
    if (mqttClient.connect(clientId, MQTT_USER, MQTT_PASS))
    {
      SER.println(F("connected."));
    }
    else
    {
      SER.printf("failed, rc=%d\n", mqttClient.state());
      delay(1000);
    }
    SER.flush();
  }
  return false;
}

void globalCallbackHandler(const IDatapoint &dp, DPValue value)
{
  // get value as char
  char value_str[15] = {0};
  value.getString(value_str, sizeof(value_str));
  SER.printf("%s - %s is %s\n", dp.getGroup(), dp.getName(), value_str);

  // MQTT
  char topic[50];
  snprintf(topic, 50, "tele/VitoWiFi/%s", dp.getName());
  mqttClient.publish(topic, value_str);

  // increment processing counter
  SER.printf("iDpProcessed: %d\n", iDpProcessed);
  SER.flush();
  iDpProcessed++;
}

void ota_check()
{
  SER.println("OTA update check ...");
  Update.installSignature(&hash, &sign);
  ESPhttpUpdate.rebootOnUpdate(true);
  ESPhttpUpdate.onStart(ota_update_started);
  ESPhttpUpdate.onEnd(ota_update_finished);
  ESPhttpUpdate.onProgress(ota_update_progress);
  ESPhttpUpdate.onError(ota_update_error);
  
  // MDNS.setHostname(deviceName);
  // MDNS.begin(deviceName);

  char ota_url[255];
  sprintf(ota_url, "%s://%s:%d/%s", OTA_PROTOCOL, OTA_HOST, OTA_PORT, OTA_PATH);
  SER.printf("OTA url: %s\n", ota_url);

  wifiClient.setTimeout(2500);  // 2.5 sec
  if (!wifiClient.connect(OTA_HOST, OTA_PORT)) {
    SER.println("No TCP connection to OTA host!");
  } 
  else
  {
    t_httpUpdate_return ret = ESPhttpUpdate.update(wifiClient, ota_url, OTA_VERSION);
    switch (ret)
    case HTTP_UPDATE_FAILED:
    {
      SER.printf("HTTP_UPDATE_FAILD Error (%d): %s\n", ESPhttpUpdate.getLastError(), ESPhttpUpdate.getLastErrorString().c_str());
      break;

    case HTTP_UPDATE_NO_UPDATES:
      SER.println("HTTP_UPDATE_NO_UPDATES");
      break;

    case HTTP_UPDATE_OK:
      SER.println("HTTP_UPDATE_OK");
      break;
    }
  }
  
  // MDNS.end();

  SER.println("OTA update check END.");
  SER.flush();
}

void cleanup_and_sleep()
{
  if (mqttClient.connected())
  {
    SER.println("MQTT disconnect ...");
    mqttClient.disconnect();
  }
  if (WiFi.isConnected())
    SER.println("WiFi disconnect ...");
    WiFi.disconnect();

  // 1e6 = 1.000.000 us = 1 second
  ulong sleepTime = 600 * 1e6; // 10 min
  if (debug)
  {
    sleepTime = 30 * 1e6; // 30 sec
    SER.printf("DeepSleep! (%.1f sec)\n", sleepTime / 1e6f);
    SER.flush();
  }

  // Deep sleep mode, the ESP8266 wakes up by itself when
  // GPIO 16 (D0) is connected to the RESET pin.
  // sleepTime in micro-seconds
  ESP.deepSleep(sleepTime);
  //
  // next awakening the ESP starts again with setup()
  //
}

void setupVitoWiFi()
{
  // VitoWiFi setup
  // this callback will be used for all DPs without specific callback
  // must be set after adding at least 1 datapoint
  VitoWiFi.setGlobalCallback(globalCallbackHandler);
  
  // use the main serial port
  // (debug output must go to Serial1)
  VitoWiFi.setup(&Serial);
  
  if (debug)
  {
    VitoWiFi.setLogger(&Serial1);
    VitoWiFi.enableLogger();
  }

  //
  // VitoWiFi reading continous in loop()
  //
}

void setup()
{
  // Use a DEBUG_PIN as hardware-defined debug on/off switch.
  // To enable serial output, connect GND and DEBUG_PIN (e.g. D1).
  // At startup, pins are configured as INPUT.
  // https://arduino-esp8266.readthedocs.io/en/latest/reference.html#digital-io
  pinMode(DEBUG_PIN, INPUT_PULLUP);
  debug = 1 - digitalRead(DEBUG_PIN);

  if (debug)
  {
    // Initialize Serial1 (Serial*ONE*) for logging/status output.
    // (not Serial/Serial0 because it is used for communication with boiler!)
    // Serial1 uses UART1 which is a transmit-only UART.
    // UART1 TX pin is D4 (GPIO2, LED!!).
    // UART1 can not be used to receive data because normally it’s RX pin is occupied for flash chip connection.
    // https://arduino-esp8266.readthedocs.io/en/latest/reference.html#serial
    SER.begin(115200);

    // diagnostic output from WiFi libraries
    SER.setDebugOutput(true);

    delay(1000);
    SER.printf("%s\n", ESP.getFullVersion().c_str());
    // https://arduino-esp8266.readthedocs.io/en/latest/boards.html#boot-messages-and-modes
    SER.printf("Boot mode: %d\n", ESP.getBootMode());
    SER.printf("Reset reason: %s\n", ESP.getResetReason().c_str());
    SER.printf("tstart: %lu\n", tstart);
  }

  // start WiFi connection
  // (automatic reconnection tries is done by ESP8266WiFi)
  SER.println("Connecting WiFi ...");
  const ulong wifiConStart = millis();
  WiFi.mode(WIFI_STA);
  WiFi.hostname(deviceName);
  WiFi.begin(WIFI_SSID, WIFI_PASS);
  // try to establish WiFi connection and get DHCP address
  // result: wl_status_t or -1 on timeout
  int8_t wifi_res = WiFi.waitForConnectResult(10000); // timeout 10 seconds (in milliseconds)
  SER.printf("WiFi connect result time: %lu\n", (millis() - wifiConStart));
  SER.printf("WiFi wifi_res: %d\n", wifi_res);

  if (WiFi.isConnected())
  {
    ota_check();

    // MQTT setup/connection
    mqttClient.setServer(MQTT_HOST, MQTT_PORT);
    if (mqtt_connect(deviceName, 3))
    {
      SER.println(F("MQTT publish ..."));
      mqttClient.publish("tele/VitoWiFi/ip", WiFi.localIP().toString().c_str());
      mqttClient.publish("tele/VitoWiFi/rssi", String(WiFi.RSSI()).c_str());
      setupVitoWiFi();
      vitoDoRead = true;
    }
  } // wifi

  if (!vitoDoRead)
    // not handling VitoWiFi, probably because no WiFi or no MQTT
    cleanup_and_sleep();
}

void loop()
{
  if (vitoDoRead)
  {
    SER.println(F("Initialize Vitotronic reading..."));
    SER.flush();
    // initiate the reading for each defined datapoint
    VitoWiFi.readAll();
    vitoDoRead = false;
    tstart = millis();
  }

  if (iDpProcessed > numDp)
  {
    SER.println("All DPs proccessed.");
    cleanup_and_sleep();
  }
  else if (tstart > 0 && (millis() - tstart > vitoTimeout))
  {
    SER.println("Timeout hit! STOP.");
    SER.println(millis() - tstart);
    cleanup_and_sleep();
  }

  // this processes all datapoints, the previously definde callback
  // is being called for each defined datapoint
  VitoWiFi.loop();
}

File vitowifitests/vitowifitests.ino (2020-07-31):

/*

This example defines three datapoints.
The first two are TEMPL type datapoints and have their own callback.
When no specific callback is attached to a datapoint, it uses the global callback.

Note the difference in return value between the callbacks:
for tempCallback uses value.getFloat() as TEMPL datapoints return a float.
globalCallback uses value.getString(char*,size_t). This method is independent of the returned type.

*/

#include <VitoWiFi.h>

VitoWiFi_setProtocol(KW);


/// Vitotronik 200 Typ KW1
/// https://github.com/openv/openv/wiki/Adressen

DPTemp outsideTemp("outsideTemp", "temperature", 0x5525);  // 2-Byte, -60..60

// Kesseltemperatur
DPTemp boilerTemp("boilerTemp", "temperature", 0x0810);  // 2-Byte, 0..150

// WW-Temperatur (Speicher)
DPTemp store1Temp("STS1", "temperature", 0x0812);  // 2-Byte, 0..150

DPTemp roomTemp("RTS", "temperature", 0x0896);
DPTemp agtsTemp("AGTS", "temperature", 0x0816);
DPTemp rltsTemp("RLTS", "temperature", 0x080A);
DPTemp vltsTemp("VLTS", "temperature", 0x080C);

// DOES NOT WORK DPTemp store2Temp("store2Temp", "temperature", 0x0813);  // 2-Byte, 0..150
// (equal to room temp) DPTemp outletTemp("outletTemp", "temperature", 0x0814);  // 2-Byte, 0..150
// DOES NOT WORK (-0.1) DPTemp setFlowTemp("setFlowTemp", "temperature", 0x2544);
// DOES NOT WORK (-0.1) DPTemp setBoilerTemp("setBoilerTemp", "temperature", 0x555A);

/*
room temp
22	309.4
21	258.1
18	257.8	283.4

reduced room temp
10	615.4
11	615.5
12	615.6
*/
DPTemp setRoomTemp("setRoomTemp", "temperature", 0x2306);
DPTemp setRoomReducedTemp("setRoomReducedTemp", "temperature", 0x2307);
// DOES NOT WORK (-0.1) DPTemp setExtRoomTemp("setExtRoomTemp", "temperature", 0x2321);

/**
 * TODO
 * SOLL Reduz. Raumtemperatur
 * SOLL WW-Temperatur
 **/

DPHours boilerRunHours("runHours", "burner", 0x08A7); // 4-Byte, 0..1150000
DPCount boilerRuns("starts", "burner", 0x088A); // 4-Byte, 0..1150000

DPMode currentOperatingMode("currentOperatingMode", "operation", 0x2500); // 1-Byte, 0..3
// DOES NOT WORK (255) DPMode operatingMode("operatingMode", "operation", 0x2323); // 1-Byte, 0..3

DPStat aim1Pump("a1m1Pump", "pump", 0x2906);
DPStat storePump("storePump", "pump", 0x0845);
DPStat circuitPump("circuitPump", "pump", 0x0846);


/*
Example output:

temperature - boilerTemp is 32.4
temperature - STS1 is 48.5
temperature - RTS is 20.0
temperature - AGTS is 20.0
temperature - RLTS is 20.0
temperature - VLTS is 20.0
temperature - setRoomTemp is 309.2
temperature - setRoomReducedTemp is 513.2
burner - runHours is 10272.3
burner - starts is 199182
operation - currentOperatingMode is 2
pump - a1m1Pump is true
pump - storePump is false
pump - circuitPump is false

*/



unsigned long waitPeriod = 60 * 1000UL;
unsigned long lastMillis = 0;




/*
void tempCallbackHandler(const IDatapoint& dp, DPValue value) {
  //float fahrenheit = 0;
  //fahrenheit = (5.0 / 9) * (value.getFloat() + 32);
  Serial1.print(dp.getGroup());
  Serial1.print(" - ");
  Serial1.print(dp.getName());
  Serial1.print(": ");
  Serial1.println(value.getFloat(), 1);  // print with 1 decimal
}


void modeCallbackHandler(const IDatapoint& dp, DPValue value) {
  Serial1.print(dp.getGroup());
  Serial1.print(" - ");
  Serial1.print(dp.getName());
  Serial1.print(" is ");
  Serial1.println(value.getU8());
}
*/


void globalCallbackHandler(const IDatapoint& dp, DPValue value) {
  Serial1.print(dp.getGroup());
  Serial1.print(" - ");
  Serial1.print(dp.getName());
  Serial1.print(" is ");
  char value_str[15] = {0};
  value.getString(value_str, sizeof(value_str));
  Serial1.println(value_str);
}


void doReading() {
  Serial1.println(lastMillis);
  VitoWiFi.readAll();
}


void setup() {
  delay(5*1000);

  
  //outsideTemp.setCallback(tempCallbackHandler);
  //boilerTemp.setCallback(tempCallbackHandler);
  //operatingMode.setCallback(modeCallbackHandler);
  
  
  VitoWiFi.setGlobalCallback(globalCallbackHandler);  // this callback will be used for all DPs without specific callback
                                                      // must be set after adding at least 1 datapoint
  VitoWiFi.setup(&Serial);
  Serial1.begin(115200);
  Serial1.println(F("Setup finished..."));
  
  // initial reading
  delay(500);
  doReading();
}

void loop() {
  if (millis() - lastMillis > waitPeriod) {
    lastMillis = millis();
    doReading();
  }
  VitoWiFi.loop();
}
